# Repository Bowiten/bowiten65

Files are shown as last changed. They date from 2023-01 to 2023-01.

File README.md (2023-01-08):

# bowiten65
a 65% keyboard pcb with a jst connector for a [unified daughterboard](https://github.com/Unified-Daughterboard/Unified-Daughterboard)
# layout
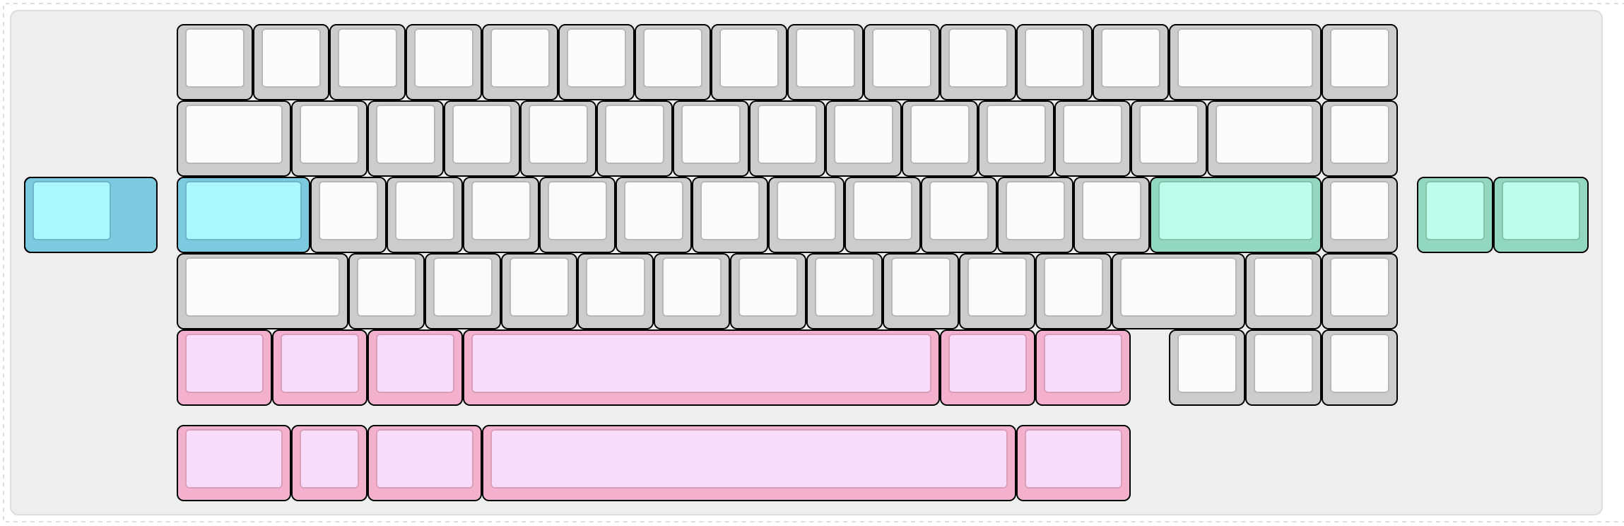
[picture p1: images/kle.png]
kle


# kicad renders
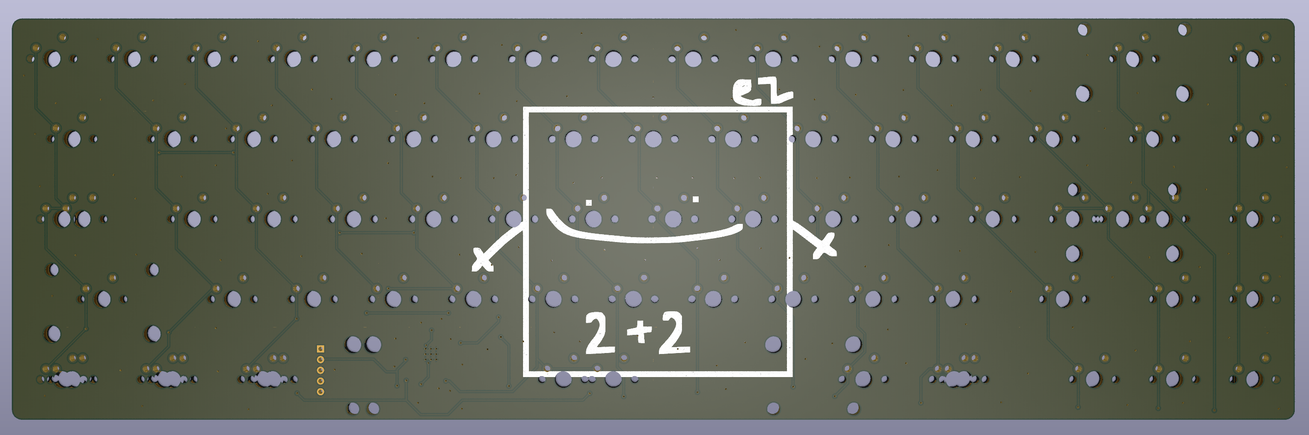
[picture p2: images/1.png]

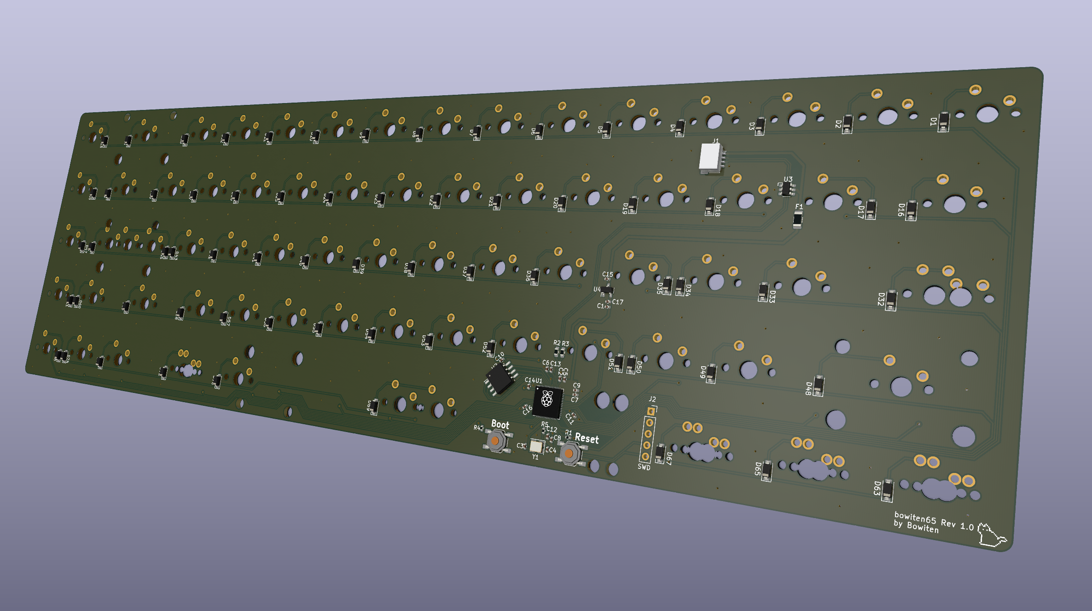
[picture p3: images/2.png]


# production
i have sent this to jlcpcb to make, although it hasn't arrived yet, so use at your own risk

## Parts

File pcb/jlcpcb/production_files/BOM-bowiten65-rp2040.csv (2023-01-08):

Comment | Designator | Footprint | LCSC
1k | R1,R4,R5 | R_0402_1005Metric | C11702
0.1u | C10,C11,C12,C13,C14,C16,C6,C7,C8,C9 | C_0402_1005Metric | C1525
10u | C1 | C_0402_1005Metric | C15525
22pF | C3,C4 | C_0402_1005Metric | C1555
SM04B | J1 | JST_SH_SM04B-SRSS-TB_1x04-1MP_P1.00mm_Horizontal | C160404
RP2040 | U1 | RP2040-QFN-56 | C2040
27 | R2,R3 | R_0603_1608Metric | C25190
Boot | SW1,SW2 | SW_SPST_TL3342 | C318884
1u | C15,C17,C2,C5 | C_0402_1005Metric | C52923
XC6206PxxxMR | U4 | SOT-23 | C5446
500mA | F1 | Fuse_1206_3216Metric | C70077
SOD-123 | D1,D10,D11,D12,D13,D14,D15,D16,D17,D18,D19,D2,D20,D21,D22,D23,D24,D25,D26,D27,D28,D29,D3,D30,D32,D33,D34,D35,D36,D37,D38,D39,D4,D40,D41,D42,D43,D45,D46,D47,D48,D49,D5,D50,D51,D52,D53,D54,D55,D56,D57,D58,D59,D6,D60,D61,D63,D65,D67,D69,D7,D70,D72,D73,D74,D75,D8,D9 | D_SOD-123 | C81598
SRV05-4 | U3 | SOT-23-6-routable | C85364
12MHz | Y1 | Crystal_SMD_3225-4Pin_3.2x2.5mm | C9002
W25Q128JVS | U2 | SOIC-8_5.23x5.23mm_P1.27mm | C97521

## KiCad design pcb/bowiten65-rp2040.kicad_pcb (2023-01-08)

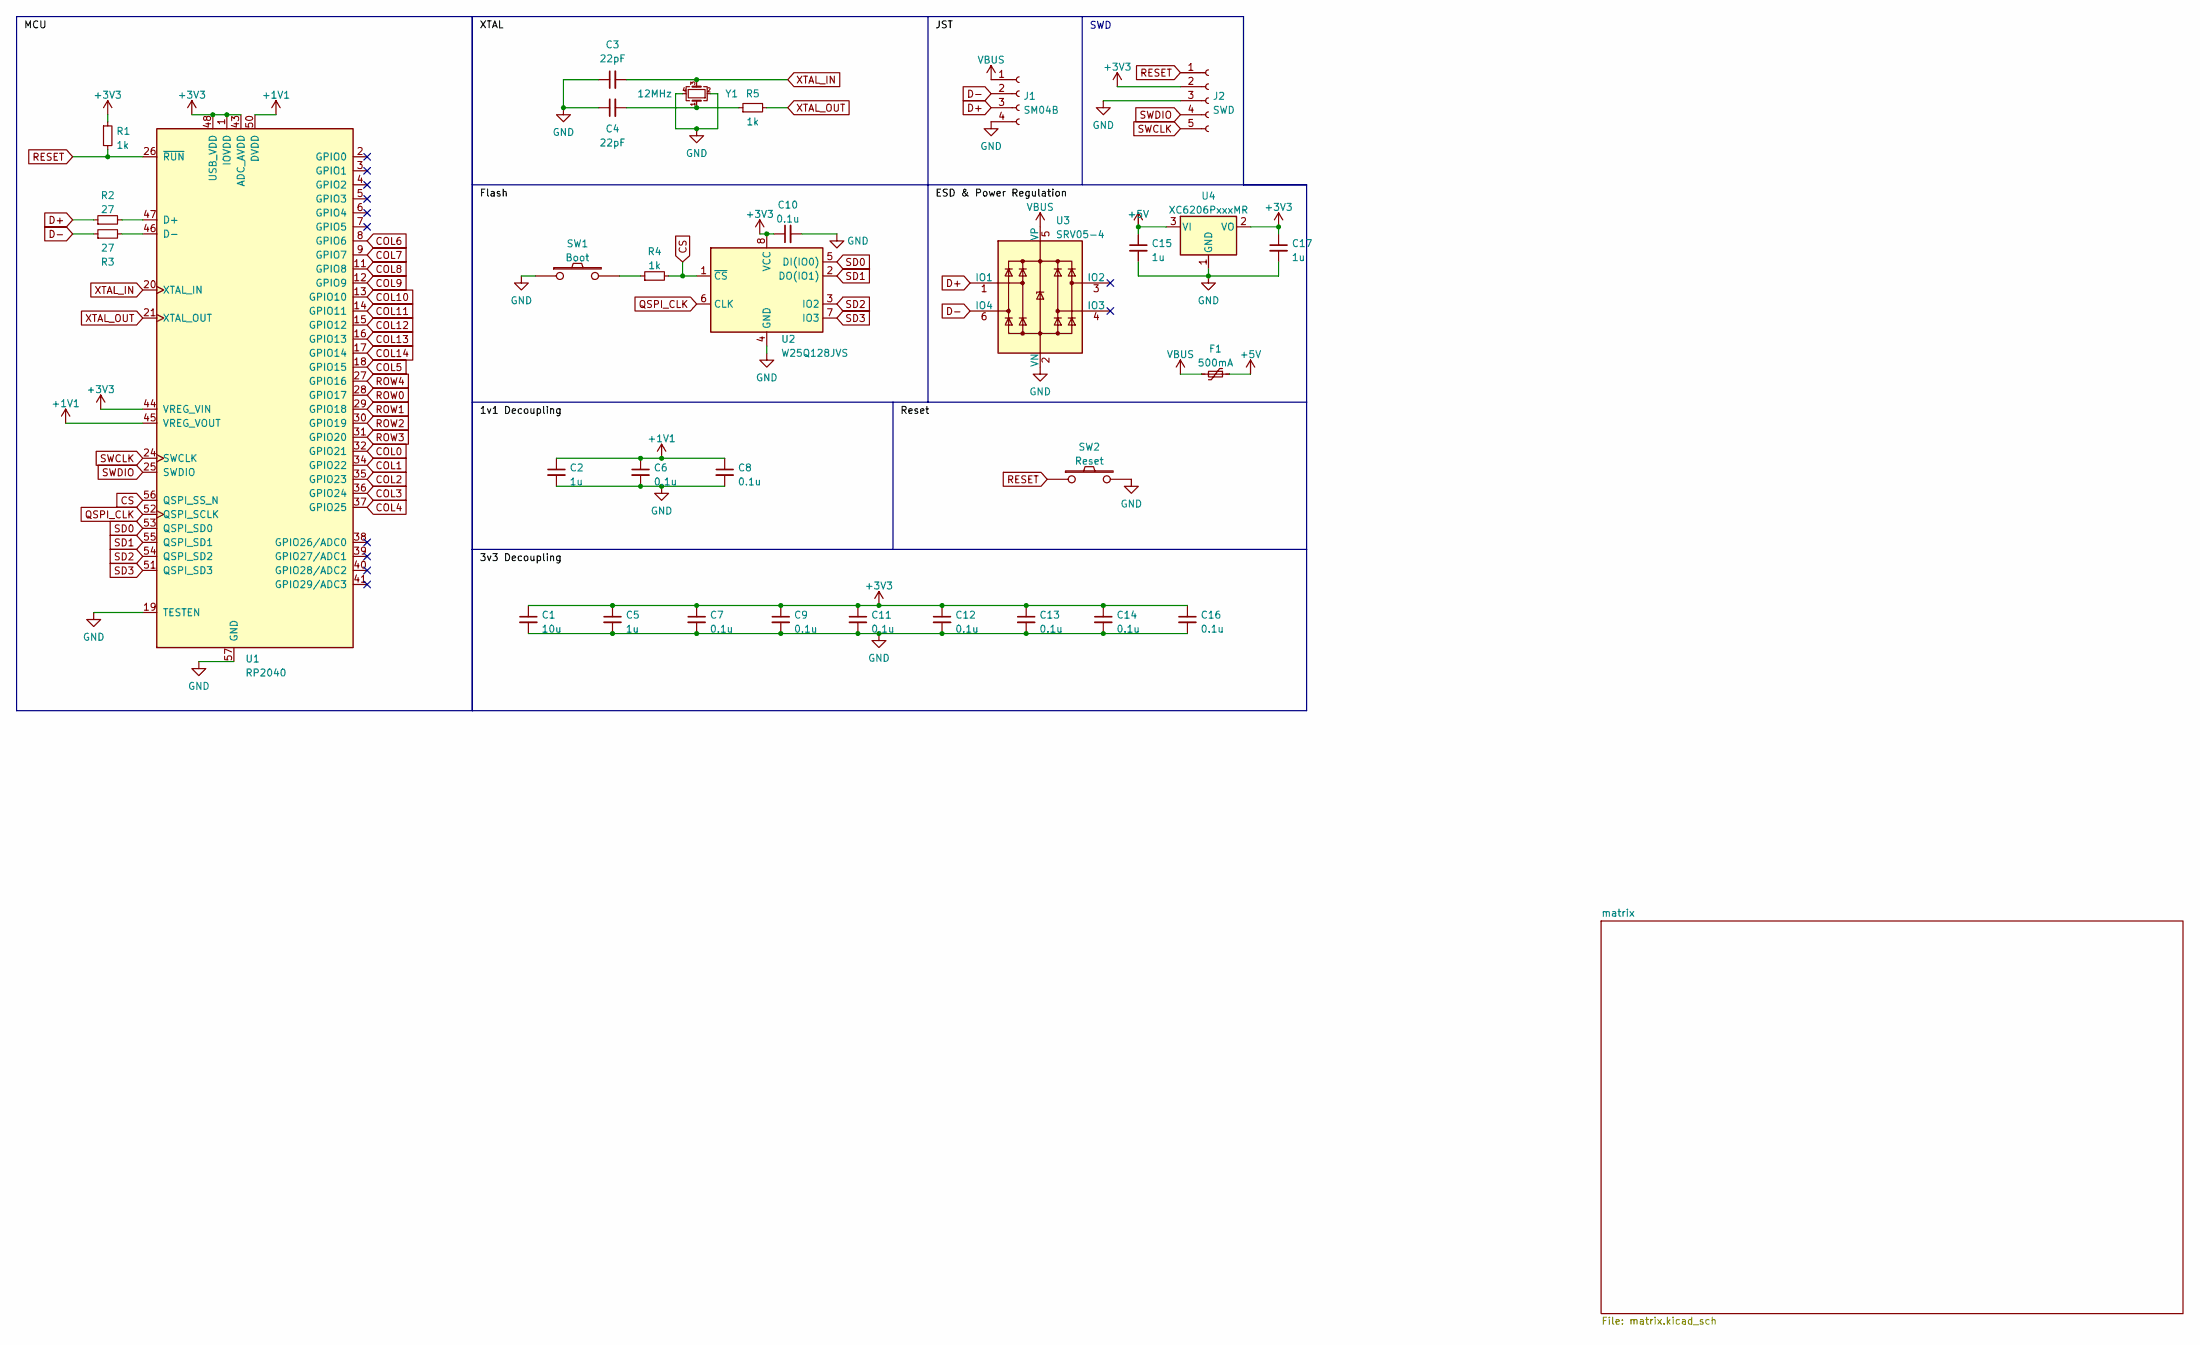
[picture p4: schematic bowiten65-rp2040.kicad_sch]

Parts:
C1: 10u; C_0402_1005Metric
C2, C5, C15, C17: 1u; C_0402_1005Metric
C3, C4: 22pF; C_0402_1005Metric
C6, C7, C8, C9, C10, C11, C12, C13, C14, C16: 0.1u; C_0402_1005Metric
F1: 500mA; Fuse_1206_3216Metric
J1: SM04B; JST_SH_SM04B-SRSS-TB_1x04-1MP_P1.00mm_Horizontal
J2: SWD; PinSocket_1x05_P2.54mm_Vertical
R1, R4, R5: 1k; R_0402_1005Metric
R2, R3: 27; R_0603_1608Metric
SW1: Boot; SW_SPST_TL3342
SW2: Reset; SW_SPST_TL3342
U1: RP2040; RP2040-QFN-56; LCSC C2040
U2: W25Q128JVS; SOIC-8_5.23x5.23mm_P1.27mm
U3: SRV05-4; SOT-23-6-routable
U4: XC6206PxxxMR; SOT-23
Y1: 12MHz; Crystal_SMD_3225-4Pin_3.2x2.5mm

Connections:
+1V1: C2.1, C6.1, C8.1, U1.23 (DVDD), U1.45 (VREG_VOUT), U1.50 (DVDD)
+3V3: C1.1, C5.1, C7.1, C9.1, C10.1, C11.1, C12.1, C13.1, C14.1, C16.1, C17.1, J2.2, R1.1, U1.1 (IOVDD), U1.10 (IOVDD), U1.22 (IOVDD), U1.33 (IOVDD), U1.42 (IOVDD), U1.43 (ADC_AVDD), U1.44 (VREG_VIN), U1.48 (USB_VDD), U1.49 (IOVDD), U2.8 (VCC), U4.2 (VO)
+5V: C15.1, F1.1, U4.3 (VI)
COL0: U1.32 (GPIO21); also elsewhere on the board
COL1: U1.34 (GPIO22); also elsewhere on the board
COL2: U1.35 (GPIO23); also elsewhere on the board
COL3: U1.36 (GPIO24); also elsewhere on the board
COL4: U1.37 (GPIO25); also elsewhere on the board
COL5: U1.18 (GPIO15); also elsewhere on the board
COL6: U1.8 (GPIO6); also elsewhere on the board
COL7: U1.9 (GPIO7); also elsewhere on the board
COL8: U1.11 (GPIO8); also elsewhere on the board
COL9: U1.12 (GPIO9); also elsewhere on the board
COL10: U1.13 (GPIO10); also elsewhere on the board
COL11: U1.14 (GPIO11); also elsewhere on the board
COL12: U1.15 (GPIO12); also elsewhere on the board
COL13: U1.16 (GPIO13); also elsewhere on the board
COL14: U1.17 (GPIO14); also elsewhere on the board
CS: R4.2, U1.56 (QSPI_SS_N), U2.1 (~CS)
D+: J1.3, R2.1, U3.1 (IO1)
D-: J1.2, R3.1, U3.6 (IO4)
GND: C1.2, C2.2, C3.1, C4.1, C5.2, C6.2, C7.2, C8.2, C9.2, C10.2, C11.2, C12.2, C13.2, C14.2, C15.2, C16.2, C17.2, J1.4, J2.3, SW1.1, SW2.2, U1.19 (TESTEN), U1.57 (GND), U2.4 (GND), U3.2 (VN), U4.1 (GND), Y1.2, Y1.4
unnamed: C4.2, R5.1, Y1.1
unnamed: R2.2, U1.47 (D+)
unnamed: R3.2, U1.46 (D-)
unnamed: R4.1, SW1.2
QSPI_CLK: U1.52 (QSPI_SCLK), U2.6 (CLK)
RESET: J2.1, R1.2, SW2.1, U1.26 (~RUN)
ROW0: U1.28 (GPIO17); also elsewhere on the board
ROW1: U1.29 (GPIO18); also elsewhere on the board
ROW2: U1.30 (GPIO19); also elsewhere on the board
ROW3: U1.31 (GPIO20); also elsewhere on the board
ROW4: U1.27 (GPIO16); also elsewhere on the board
SD0: U1.53 (QSPI_SD0), U2.5 (DI(IO0))
SD1: U1.55 (QSPI_SD1), U2.2 (DO(IO1))
SD2: U1.54 (QSPI_SD2), U2.3 (IO2)
SD3: U1.51 (QSPI_SD3), U2.7 (IO3)
SWCLK: J2.5, U1.24 (SWCLK)
SWDIO: J2.4, U1.25 (SWDIO)
VBUS: F1.2, J1.1, U3.5 (VP)
XTAL_IN: C3.2, U1.20 (XTAL_IN), Y1.3
XTAL_OUT: R5.2, U1.21 (XTAL_OUT)

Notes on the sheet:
SWD

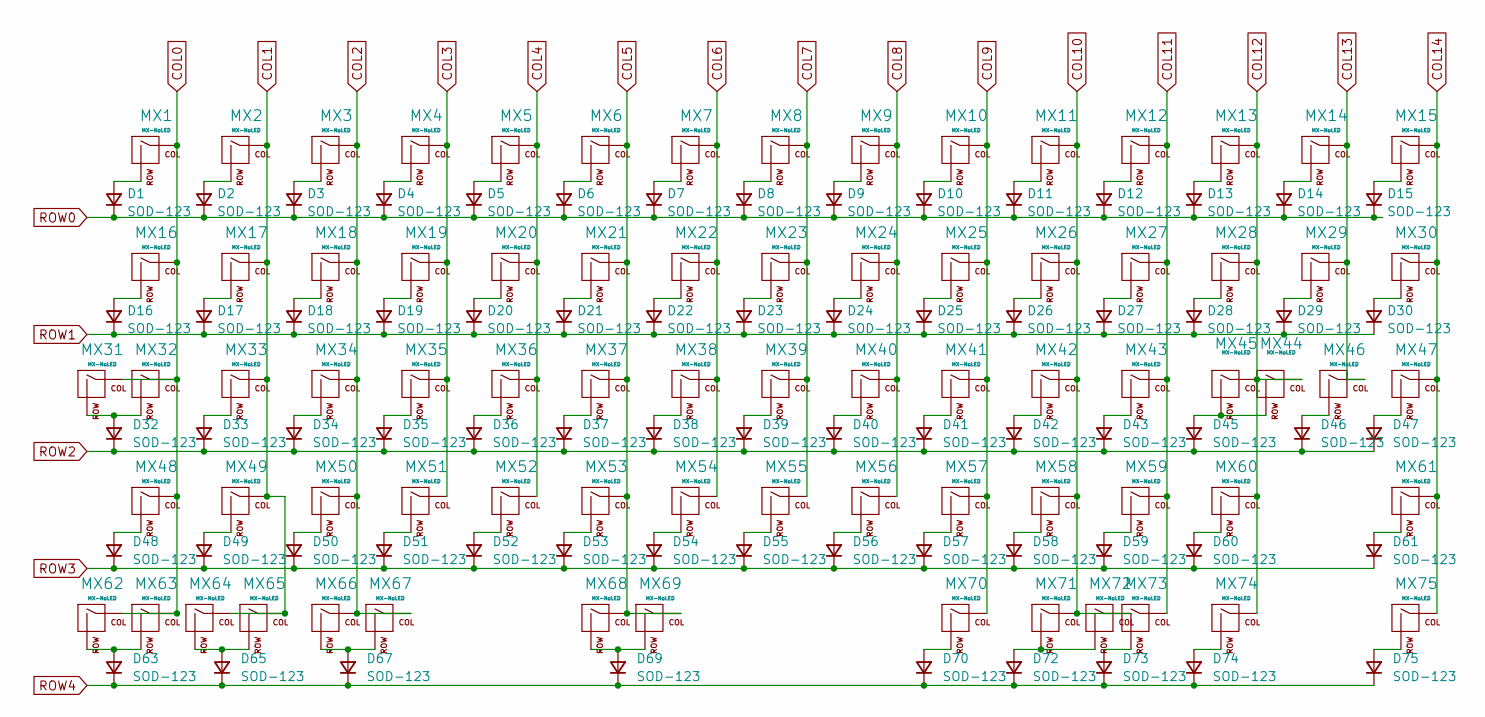
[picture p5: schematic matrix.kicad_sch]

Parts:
D1, D2, D3, D4, D5, D6, D7, D8, D9, D10, D11, D12, D13, D14, D15, D16, D17, D18, D19, D20, D21, D22, D23, D24, D25, D26, D27, D28, D29, D30, D32, D33, D34, D35, D36, D37, D38, D39, D40, D41, D42, D43, D45, D46, D47, D48, D49, D50, D51, D52, D53, D54, D55, D56, D57, D58, D59, D60, D61, D63, D65, D67, D69, D70, D72, D73, D74, D75: SOD-123; D_SOD-123; LCSC C33221
MX1, MX2, MX3, MX4, MX5, MX6, MX7, MX8, MX9, MX10, MX11, MX12, MX13, MX15, MX17, MX18, MX19, MX20, MX21, MX22, MX23, MX24, MX25, MX26, MX27, MX28, MX30, MX33, MX34, MX35, MX36, MX37, MX38, MX39, MX40, MX41, MX42, MX43, MX44, MX47, MX49, MX50, MX51, MX52, MX53, MX54, MX55, MX56, MX57, MX58, MX60, MX61, MX65, MX73, MX74, MX75: MX-NoLED; MXOnly-1U-NoLED
MX14: MX-NoLED; MXOnly-2U-NoLED
MX16, MX29, MX63, MX67, MX71: MX-NoLED; MXOnly-1.5U-NoLED
MX31, MX46, MX62, MX64, MX66, MX70, MX72: MX-NoLED; MXOnly-1.25U-NoLED
MX32, MX59: MX-NoLED; MXOnly-1.75U-NoLED
MX45, MX48: MX-NoLED; MXOnly-2.25U-NoLED
MX68: MX-NoLED; MXOnly-6.25U-ReversedStabilizers-NoLED
MX69: MX-NoLED; MXOnly-7U-ReversedStabilizers-NoLED

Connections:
COL0: MX1.1 (COL), MX16.1 (COL), MX31.1 (COL), MX32.1 (COL), MX48.1 (COL), MX62.1 (COL), MX63.1 (COL); also elsewhere on the board
COL1: MX2.1 (COL), MX17.1 (COL), MX33.1 (COL), MX49.1 (COL), MX64.1 (COL), MX65.1 (COL); also elsewhere on the board
COL2: MX3.1 (COL), MX18.1 (COL), MX34.1 (COL), MX50.1 (COL), MX66.1 (COL), MX67.1 (COL); also elsewhere on the board
COL3: MX4.1 (COL), MX19.1 (COL), MX35.1 (COL), MX51.1 (COL); also elsewhere on the board
COL4: MX5.1 (COL), MX20.1 (COL), MX36.1 (COL), MX52.1 (COL); also elsewhere on the board
COL5: MX6.1 (COL), MX21.1 (COL), MX37.1 (COL), MX53.1 (COL), MX68.1 (COL), MX69.1 (COL); also elsewhere on the board
COL6: MX7.1 (COL), MX22.1 (COL), MX38.1 (COL), MX54.1 (COL); also elsewhere on the board
COL7: MX8.1 (COL), MX23.1 (COL), MX39.1 (COL), MX55.1 (COL); also elsewhere on the board
COL8: MX9.1 (COL), MX24.1 (COL), MX40.1 (COL), MX56.1 (COL); also elsewhere on the board
COL9: MX10.1 (COL), MX25.1 (COL), MX41.1 (COL), MX57.1 (COL), MX70.1 (COL); also elsewhere on the board
COL10: MX11.1 (COL), MX26.1 (COL), MX42.1 (COL), MX58.1 (COL), MX71.1 (COL), MX72.1 (COL); also elsewhere on the board
COL11: MX12.1 (COL), MX27.1 (COL), MX43.1 (COL), MX59.1 (COL), MX73.1 (COL); also elsewhere on the board
COL12: MX13.1 (COL), MX28.1 (COL), MX44.1 (COL), MX45.1 (COL), MX60.1 (COL), MX74.1 (COL); also elsewhere on the board
COL13: MX14.1 (COL), MX29.1 (COL), MX46.1 (COL); also elsewhere on the board
COL14: MX15.1 (COL), MX30.1 (COL), MX47.1 (COL), MX61.1 (COL), MX75.1 (COL); also elsewhere on the board
unnamed: D1.2 (A), MX1.2 (ROW)
unnamed: D2.2 (A), MX2.2 (ROW)
unnamed: D3.2 (A), MX3.2 (ROW)
unnamed: D4.2 (A), MX4.2 (ROW)
unnamed: D5.2 (A), MX5.2 (ROW)
unnamed: D6.2 (A), MX6.2 (ROW)
unnamed: D7.2 (A), MX7.2 (ROW)
unnamed: D8.2 (A), MX8.2 (ROW)
unnamed: D9.2 (A), MX9.2 (ROW)
unnamed: D10.2 (A), MX10.2 (ROW)
unnamed: D11.2 (A), MX11.2 (ROW)
unnamed: D12.2 (A), MX12.2 (ROW)
unnamed: D13.2 (A), MX13.2 (ROW)
unnamed: D14.2 (A), MX14.2 (ROW)
unnamed: D15.2 (A), MX15.2 (ROW)
unnamed: D16.2 (A), MX16.2 (ROW)
unnamed: D17.2 (A), MX17.2 (ROW)
unnamed: D18.2 (A), MX18.2 (ROW)
unnamed: D19.2 (A), MX19.2 (ROW)
unnamed: D20.2 (A), MX20.2 (ROW)
unnamed: D21.2 (A), MX21.2 (ROW)
unnamed: D22.2 (A), MX22.2 (ROW)
unnamed: D23.2 (A), MX23.2 (ROW)
unnamed: D24.2 (A), MX24.2 (ROW)
unnamed: D25.2 (A), MX25.2 (ROW)
unnamed: D26.2 (A), MX26.2 (ROW)
unnamed: D27.2 (A), MX27.2 (ROW)
unnamed: D28.2 (A), MX28.2 (ROW)
unnamed: D29.2 (A), MX29.2 (ROW)
unnamed: D30.2 (A), MX30.2 (ROW)
unnamed: D32.2 (A), MX31.2 (ROW), MX32.2 (ROW)
unnamed: D33.2 (A), MX33.2 (ROW)
unnamed: D34.2 (A), MX34.2 (ROW)
unnamed: D35.2 (A), MX35.2 (ROW)
unnamed: D36.2 (A), MX36.2 (ROW)
unnamed: D37.2 (A), MX37.2 (ROW)
unnamed: D38.2 (A), MX38.2 (ROW)
unnamed: D39.2 (A), MX39.2 (ROW)
unnamed: D40.2 (A), MX40.2 (ROW)
unnamed: D41.2 (A), MX41.2 (ROW)
unnamed: D42.2 (A), MX42.2 (ROW)
unnamed: D43.2 (A), MX43.2 (ROW)
unnamed: D45.2 (A), MX44.2 (ROW), MX45.2 (ROW)
unnamed: D46.2 (A), MX46.2 (ROW)
unnamed: D47.2 (A), MX47.2 (ROW)
unnamed: D48.2 (A), MX48.2 (ROW)
unnamed: D49.2 (A), MX49.2 (ROW)
unnamed: D50.2 (A), MX50.2 (ROW)
unnamed: D51.2 (A), MX51.2 (ROW)
unnamed: D52.2 (A), MX52.2 (ROW)
unnamed: D53.2 (A), MX53.2 (ROW)
unnamed: D54.2 (A), MX54.2 (ROW)
unnamed: D55.2 (A), MX55.2 (ROW)
unnamed: D56.2 (A), MX56.2 (ROW)
unnamed: D57.2 (A), MX57.2 (ROW)
unnamed: D58.2 (A), MX58.2 (ROW)
unnamed: D59.2 (A), MX59.2 (ROW)
unnamed: D60.2 (A), MX60.2 (ROW)
unnamed: D61.2 (A), MX61.2 (ROW)
unnamed: D63.2 (A), MX62.2 (ROW), MX63.2 (ROW)
unnamed: D65.2 (A), MX64.2 (ROW), MX65.2 (ROW)
unnamed: D67.2 (A), MX66.2 (ROW), MX67.2 (ROW)
unnamed: D69.2 (A), MX68.2 (ROW), MX69.2 (ROW)
unnamed: D70.2 (A), MX70.2 (ROW)
unnamed: D72.2 (A), MX71.2 (ROW), MX72.2 (ROW)
unnamed: D73.2 (A), MX73.2 (ROW)
unnamed: D74.2 (A), MX74.2 (ROW)
unnamed: D75.2 (A), MX75.2 (ROW)
ROW0: D1.1 (K), D2.1 (K), D3.1 (K), D4.1 (K), D5.1 (K), D6.1 (K), D7.1 (K), D8.1 (K), D9.1 (K), D10.1 (K), D11.1 (K), D12.1 (K), D13.1 (K), D14.1 (K), D15.1 (K); also elsewhere on the board
ROW1: D16.1 (K), D17.1 (K), D18.1 (K), D19.1 (K), D20.1 (K), D21.1 (K), D22.1 (K), D23.1 (K), D24.1 (K), D25.1 (K), D26.1 (K), D27.1 (K), D28.1 (K), D29.1 (K), D30.1 (K); also elsewhere on the board
ROW2: D32.1 (K), D33.1 (K), D34.1 (K), D35.1 (K), D36.1 (K), D37.1 (K), D38.1 (K), D39.1 (K), D40.1 (K), D41.1 (K), D42.1 (K), D43.1 (K), D45.1 (K), D46.1 (K), D47.1 (K); also elsewhere on the board
ROW3: D48.1 (K), D49.1 (K), D50.1 (K), D51.1 (K), D52.1 (K), D53.1 (K), D54.1 (K), D55.1 (K), D56.1 (K), D57.1 (K), D58.1 (K), D59.1 (K), D60.1 (K), D61.1 (K); also elsewhere on the board
ROW4: D63.1 (K), D65.1 (K), D67.1 (K), D69.1 (K), D70.1 (K), D72.1 (K), D73.1 (K), D74.1 (K), D75.1 (K); also elsewhere on the board

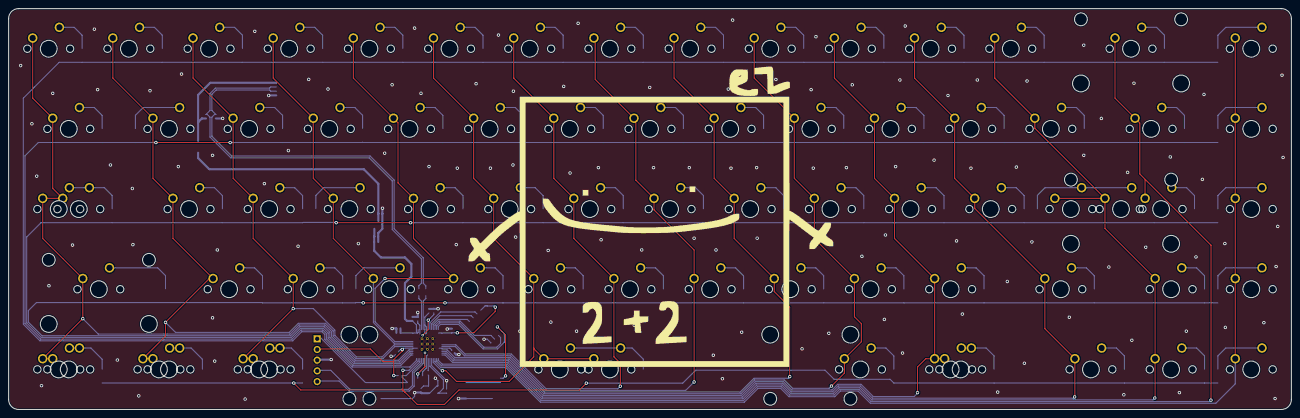
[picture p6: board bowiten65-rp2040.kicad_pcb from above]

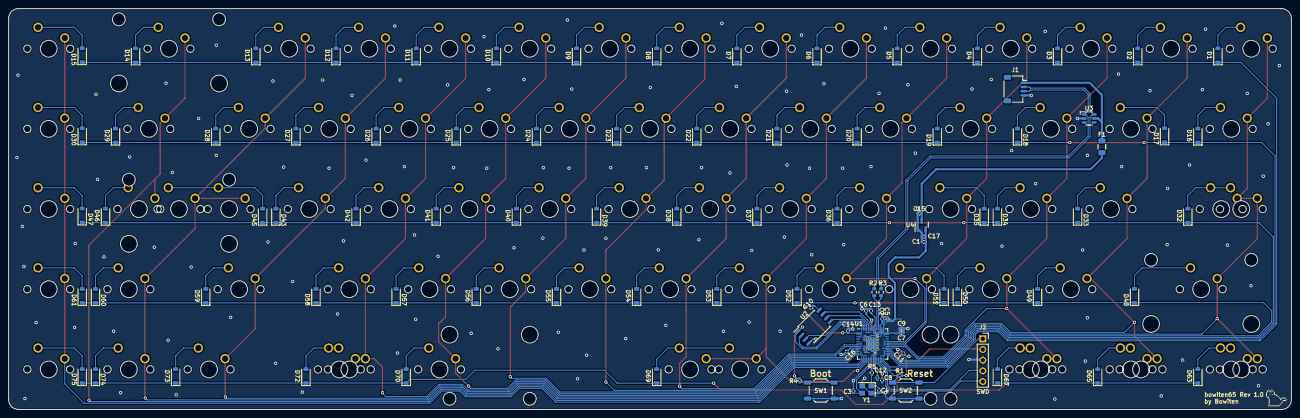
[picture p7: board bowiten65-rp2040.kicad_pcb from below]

Board: 2 copper layers, 304.8 x 95.2 mm, 175 parts (100 on the bottom side), 110 nets.
